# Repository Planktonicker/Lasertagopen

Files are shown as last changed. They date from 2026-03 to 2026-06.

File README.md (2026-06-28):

There is an error with the PCB wiring for the battery, please do not use the PCB design, or edit it

🔫 Open Laser Tag (ESP32 Arena System)

Welcome to Open Laser Tag, a fully open-source, highly scalable, and professional-grade laser tag system built on the ESP32 platform.
This project allows you to build custom laser tag blasters with OLED HUDs, tactile controls, and massive outdoor range, all tied together by a central "Cheap Yellow Display" (CYD) touch server that hosts a live, cyberpunk-themed web dashboard for up to 64 players.
The original intent was to create an easy to setup lasertag game to undercut vendors who charge exhorbitant prices for a game. This hopefullt allows more educator such as myself to have access to easily available laser tag.

✨ Key Features

Massive Scalability: Play backyard games (up to 10 players) using the CYD's built-in Wi-Fi Hub, or scale up to massive 64-player arena matches using a standard, offline Wi-Fi router.
Smart Networking: Blasters and servers automatically search for a central router. If one isn't found, they seamlessly fall back to local Hub mode. No internet connection is ever required.
Live Web Dashboard: The CYD Server hosts a mobile-responsive web dashboard. Game masters can change rules, start/stop matches, and view live K/D/A telemetry from their smartphones.
Esports Scoreboard Overlay: The web dashboard features a dynamic, full-screen overlay for laptops/TVs that automatically divides into quadrants based on active teams (perfect for spectator displays).
Extreme Range Optics: Utilizes a custom 5V-driven TSAL6100 IR circuit paired with a 20mm plano-convex lens for 50+ meter outdoor "sniper" range.
On-the-fly Configuration: Blasters feature a hidden configuration menu (via the rotary encoder) to change Gun IDs, Teams, and Roles without needing to reflash the code.

🛠️ Hardware Requirements

The system is broken down into two main components: The Blasters and The Server.

The Blaster (Gun) BOM

Microcontroller: ESP32 38-Pin DevKitC (WROOM-32)
Display: 1.3" SH1106 I2C OLED (White or Blue)
Controls: * KY-040 Rotary Encoder (For volume, reloading, and menus)
KW12 Microswitch (For the main trigger)
Audio: Passive Piezo Buzzer (5V)

IR Optics:

Transmitter: TSAL6100 (940nm 5mm LED) + 2N2222 Transistor + 20Ω Resistor and 1000ohm resistor
Receiver: TSOP38238 (38kHz) x 3
Lens: 20mm Plano-Convex Lens (Mounted exactly ~21.7mm from the IR LED die)

Power: 18650 Battery + V8 Battery Shield (1-way) + Master Toggle Switch

The Server (Command Center)

Microcontroller/Display: ESP32-2432S028R "Cheap Yellow Display" (2.8" TFT with Touch)
(Alternative): Standard ESP32 with a 2.2" ST7789 TFT display.
Network: Any cheap, standard Wi-Fi router (for 50+ player games).

🔌 Crucial Wiring & Hardware Notes

If you are building this from scratch, pay close attention to these engineering details:
The 5V Laser Circuit: The ESP32's 3.3V pins cannot provide enough power for outdoor IR range. You must route 5V directly from the battery shield to the TSAL6100 LED, using a 2N2222 transistor as a switch controlled by the ESP32 (protected by a 1kΩ base resistor).
Battery Voltage Divider: Because the 18650 shield regulates output to a flat 5V, the ESP32 cannot natively read the battery's decay. You must wire a 100kΩ/100kΩ voltage divider directly from the raw battery (B+ pad) to an ESP32 ADC pin (IO34) to get accurate battery percentages on the OLED.
Multiple IR Receivers: If you want to add sensors to a headband or the sides of the blaster, wire multiple TSOP38238 receivers in Parallel (All VCCs together, all GNDs together, all OUTs together).
Trigger Pull-ups: The KW12 Trigger microswitch connects to GND and an ESP32 GPIO pin. No external resistors are needed; the software uses INPUT_PULLUP.

💻 Software & Installation

This project is built using PlatformIO (via VS Code). Using the Arduino IDE is not recommended due to library dependency management.

Setup Instructions

Clone this repository and open the project folder in VS Code with the PlatformIO extension installed.
The platformio.ini file will automatically download the correct libraries (like LovyanGFX or TFT_eSPI / Adafruit_ILI9341 depending on your screen hardware).
Connect your ESP32 or CYD via USB.
Click Upload in PlatformIO.

📡 Network & Operation Guide

How to Start a Match

(Optional) Power the Router: If playing a massive game, plug in your dedicated LaserArena Wi-Fi router. (Do not plug it into the internet).
Boot the CYD Server: Plug the CYD into a USB power bank. It will search for the router for 10 seconds.
If it finds it, it joins and shows a green [LA] tag.
If not, it creates its own Wi-Fi bubble and shows a yellow [LAH] tag.

Boot the Blasters: Turn on the guns. They will automatically hunt for the network and sync with the CYD Server.
Join the Dashboard: Connect your Smartphone or Laptop to the Wi-Fi network (LaserArena or LaserTag_Hub).

⚠️ IMPORTANT: Accessing the Web Dashboard

Modern devices (especially MacBooks and iPhones) use Secure DNS or Apple Private Relay, which breaks custom local domain names like lasertagarena.game.
To guarantee access to the command center, type the raw IP address directly into your browser:
If using the Router [LA]: Go to http://192.168.1.100
If using the CYD Hub [LAH]: Go to http://192.168.4.1

Managing Teams

You can change a player's team in three different ways:
On the Gun: The player turns the rotary encoder while in the lobby.
On the CYD: The Game Master taps the player's ID on the physical CYD Scoreboard tab.
On the Web App: The Game Master taps the player's row on their smartphone dashboard.

3D prints

Included the F3D files in case you want to edit, the main body hosues all the goods, the extention helps to convert it into a full tagger with grip and nerf stock adapter. Do note you need 3 IR receiver fore this build, feel free to add or remove to your needs. wire them in parrallel

📜 License

lasertagopen is open-source and licensed under the [GNU AFFERO GENERAL PUBLIC LICENSE
Version 3].
If you wish to use this project in a closed-source or proprietary
commercial product, please contact chengxinze96@gmail,com for a commercial license.
Build, modify, and dominate the arena!

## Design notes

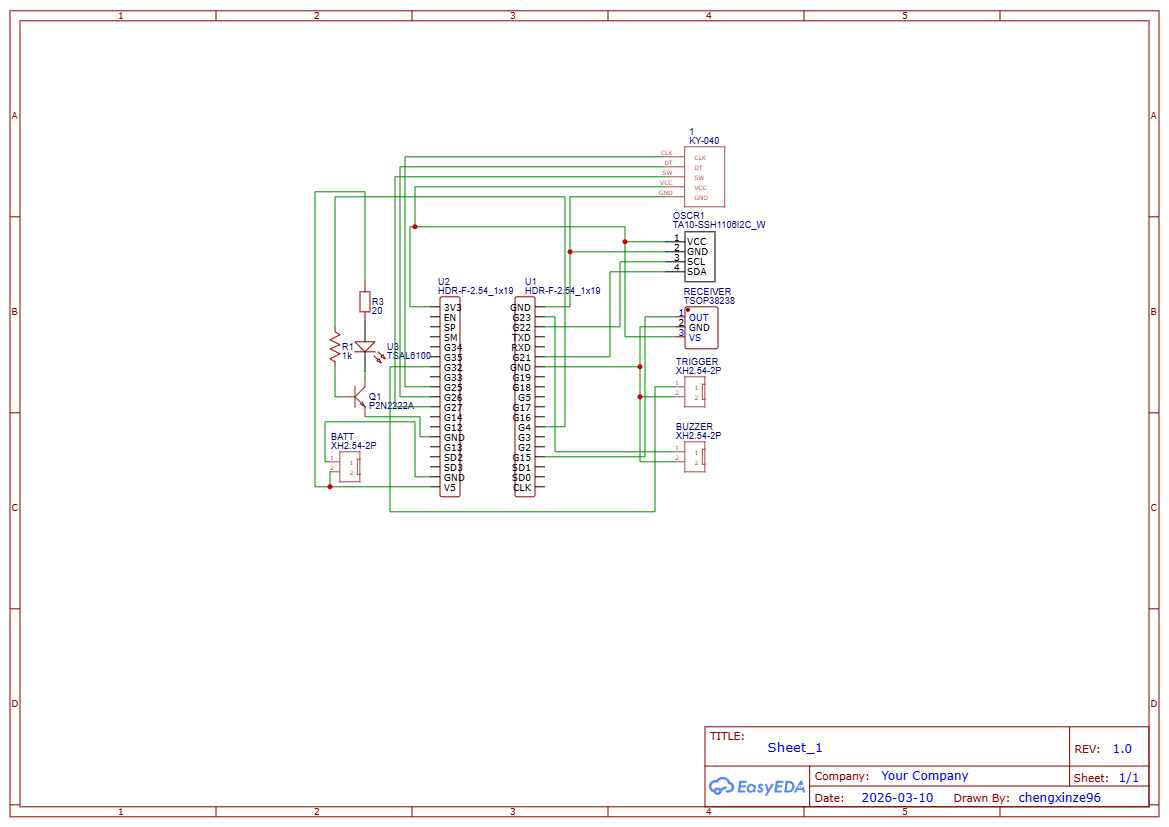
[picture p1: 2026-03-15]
pcb/Schematic_lasertag_2026-03-15.png

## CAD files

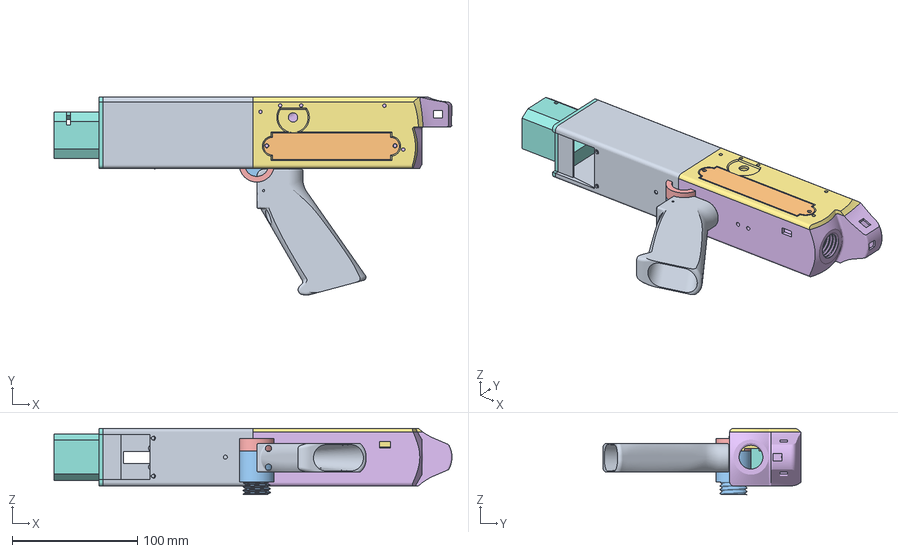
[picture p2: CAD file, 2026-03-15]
3dpint/LASERTAGV3.3mf
318.0 x 158.4 x 53.0 mm
AR_Pistol_Grip_Smooth (1)
Battery cover
Main body
Panel
Stock
pistol grip body

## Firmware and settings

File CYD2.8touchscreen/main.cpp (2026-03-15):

#include <Arduino.h>
#include <WiFi.h>
#include <WebServer.h>
#include <DNSServer.h>
#include <SPI.h>
#include <Adafruit_GFX.h>
#include <Adafruit_ILI9341.h>
#include <XPT2046_Touchscreen.h>

// --- CYD TOUCHSCREEN PINS (VSPI) ---
#define XPT2046_IRQ  36
#define XPT2046_MOSI 32
#define XPT2046_MISO 39
#define XPT2046_CLK  25
#define XPT2046_CS   33

// --- CYD TFT SCREEN PINS (HSPI) ---
#define TFT_MISO 12
#define TFT_MOSI 13
#define TFT_CLK  14
#define TFT_CS   15
#define TFT_DC   2
#define TFT_RST  -1
#define TFT_BL   21 // Backlight

// Initialize dual SPI buses for CYD
XPT2046_Touchscreen ts(XPT2046_CS, XPT2046_IRQ);
SPIClass tftSpi = SPIClass(HSPI);
Adafruit_ILI9341 tft = Adafruit_ILI9341(&tftSpi, TFT_DC, TFT_CS, TFT_RST);
WebServer server(80);
DNSServer dnsServer; 
const byte DNS_PORT = 53;

// --- SERVER VARIABLES ---
const char* apSSID = "LaserTag_Hub";
const char* apPass = "pewpewpew";
const char* routerSSID   = "LaserArena";
const char* routerPass   = "pewpewpew";
const char* customDomain = "lasertagarena.game"; 
bool usingExternalRouter = false; 

// --- GAME STATE SYNCED TO GUNS ---
int hostStatus = 0; // 0=Lobby, 1=Running, 2=Kill All
int baseDamage = 50; 
int configLives = 3;
int configMags = 5;
int configHealth = 100;
int gameMode = 0; // 0=Combat, 1=Unlimited

#define MAX_PLAYERS 64

// --- SCOREBOARD TRACKING ---
struct PlayerRecord {
  int id;
  int team;
  int kills;
  int deaths;
  int assists;
  bool active;
};
PlayerRecord players[MAX_PLAYERS];
int playerCount = 0;

// --- UI STATE ---
int currentScreen = 0; // 0=Main, 1=Setup1, 2=Setup2, 4=Scoreboard
unsigned long gameStartTime = 0;
unsigned long lastTimerUpdate = 0;
int scoreboardOffset = 0; // Tracks which page of players we are viewing

// Cyberpunk / Neon Colors
#define COLOR_WHITE     0xFFFF
#define COLOR_BLACK     0x0000
#define C_BG            tft.color565(5, 5, 10)    // Void Black/Deep Blue
#define C_CYAN          tft.color565(0, 255, 255) // Primary Neon
#define C_MAGENTA       tft.color565(255, 0, 255) // Secondary Neon
#define C_GREEN         tft.color565(0, 255, 100) // Success/Active
#define C_RED           tft.color565(255, 0, 100) // Warning/Kill
#define C_YELLOW        tft.color565(255, 255, 0) // Alerts
#define C_GREY          tft.color565(80, 80, 100) // Inactive outlines

// --- FORWARD DECLARATIONS ---
void drawMainScreen();
void drawSetupScreen1();
void drawSetupScreen2();
void drawScoreboardScreen();

PlayerRecord* getPlayer(int id) {
  if (id <= 0) return nullptr;
  for(int i=0; i<MAX_PLAYERS; i++) {
    if(players[i].active && players[i].id == id) return &players[i];
  }
  for(int i=0; i<MAX_PLAYERS; i++) {
    if(!players[i].active) {
      players[i].id = id;
      players[i].team = 1;
      players[i].kills = 0;
      players[i].deaths = 0;
      players[i].assists = 0;
      players[i].active = true;
      playerCount++;
      return &players[i];
    }
  }
  return nullptr;
}

// --- WEB SERVER ENDPOINTS ---
void handleRoot() {
  int teamKills[5] = {0, 0, 0, 0, 0};
  bool teamActive[5] = {false, false, false, false, false};
  int activeTeamCount = 0; 
  
  for(int i = 0; i < MAX_PLAYERS; i++) {
    if(players[i].active) {
      teamKills[players[i].team] += players[i].kills;
      teamActive[players[i].team] = true;
    }
  }
  
  // Count how many teams are playing to calculate grid layout
  for(int t = 1; t <= 4; t++) {
    if(teamActive[t]) activeTeamCount++;
  }

  String html = "<!DOCTYPE html><html><head><title>Arena Command</title>";
  html += "<meta name='viewport' content='width=device-width, initial-scale=1.0, maximum-scale=1.0, user-scalable=no, viewport-fit=cover'>";
  
  html += "<style>";
  html += "* { box-sizing: border-box; -webkit-tap-highlight-color: transparent; }";
  html += "body { font-family: -apple-system, system-ui, sans-serif; background: #050510; color: #0ff; margin: 0; padding: env(safe-area-inset-top) 15px 40px 15px; }";
  html += ".card { background: rgba(0, 255, 255, 0.08); padding: 20px; border: 1px solid #0ff; border-radius: 20px; margin-bottom: 20px; box-shadow: 0 10px 40px rgba(0,0,0,0.7); }";
  html += "h1 { font-size: 26px; text-align: center; color: #fff; text-shadow: 0 0 15px #0ff; margin: 25px 0; letter-spacing: 1px; }";
  html += "h2 { font-size: 13px; margin-top: 0; border-bottom: 1px solid rgba(0, 255, 255, 0.2); padding-bottom: 12px; margin-bottom: 15px; text-transform: uppercase; letter-spacing: 2px; color: rgba(255,255,255,0.7); }";
  
  html += "button { width: 100%; padding: 22px; margin-bottom: 15px; background: #001a1a; border: 2px solid #0ff; color: #0ff; border-radius: 14px; font-weight: bold; font-size: 18px; transition: 0.1s; cursor: pointer; }";
  html += "button:active { transform: scale(0.97); background: #0ff; color: #000; }";
  html += ".btn-red { border-color: #f0f; color: #f0f; background: #1a001a; }";
  html += ".btn-green { border-color: #0f0; color: #0f0; background: #001a00; }";
  
  html += ".grid { display: flex; flex-wrap: wrap; gap: 15px; }";
  html += ".grid > div { flex: 1 1 calc(50% - 15px); min-width: 100px; }"; // Reduced min-width slightly to fit 5 boxes better
  html += ".score-grid { display: grid; grid-template-columns: repeat(auto-fit, minmax(280px, 1fr)); gap: 20px; }";
  
  html += "label { font-size: 10px; display: block; margin-bottom: 8px; color: #fff; opacity: 0.8; font-weight: 800; letter-spacing: 1px; }";
  html += "input, select { width: 100%; padding: 16px; background: #000; color: #fff; border: 1px solid #0ff; border-radius: 12px; font-size: 18px; outline: none; -webkit-appearance: none; }";
  
  html += "table { width: 100%; text-align: center; border-collapse: collapse; margin-top: 10px; }";
  html += "th, td { padding: 12px 5px; border-bottom: 1px solid rgba(255, 255, 255, 0.1); font-size: 15px; }";
  html += "th { font-size: 10px; opacity: 0.5; color: #fff; }";
  html += ".kd-val { font-weight: bold; color: #fff; }";
  html += "tr.player-row { cursor: pointer; transition: background 0.2s; }"; 
  html += "tr.player-row:hover { background: rgba(255, 255, 255, 0.05); }"; 
  html += "tr.player-row:active { background: rgba(0, 255, 255, 0.2); }"; 

  // --- ESPORTS FULL SCREEN CSS ---
  html += "#fs-overlay{display:none;position:fixed;top:0;left:0;width:100vw;height:100vh;background-color:#050510;background-size:40px 40px;background-image:linear-gradient(to right, rgba(0,255,255,0.05) 1px, transparent 1px),linear-gradient(to bottom, rgba(0,255,255,0.05) 1px, transparent 1px);z-index:9999;padding:30px;flex-direction:column;overflow:hidden;box-sizing:border-box;} ";
  html += "#fs-overlay.active{display:flex;} ";
  html += ".fs-header{display:flex;justify-content:space-between;align-items:center;margin-bottom:20px;} ";
  html += ".fs-title{font-size:28px;font-weight:900;letter-spacing:2px;color:#fff;margin:0;text-shadow:0 0 10px rgba(255,255,255,0.5);} ";
  html += ".fs-grid{display:grid;gap:30px;flex:1;min-height:0;} ";
  html += ".fs-grid[data-teams='1']{grid-template-columns:1fr;} ";
  html += ".fs-grid[data-teams='2']{grid-template-columns:1fr 1fr;} ";
  html += ".fs-grid[data-teams='3'],.fs-grid[data-teams='4']{grid-template-columns:1fr 1fr;grid-template-rows:1fr 1fr;} ";
  html += ".fs-team-panel{border:2px solid;border-radius:12px;display:flex;flex-direction:column;background:rgba(0,0,0,0.5);box-shadow:inset 0 0 50px rgba(0,0,0,0.8);overflow:hidden;} ";
  html += ".fs-team-header{padding:20px;display:flex;justify-content:space-between;align-items:center;background:rgba(255,255,255,0.1);border-bottom:2px solid;} ";
  html += ".fs-team-name{font-size:24px;font-weight:900;letter-spacing:2px;} ";
  html += ".fs-team-score{font-size:32px;font-weight:900;} ";
  html += ".fs-table-wrap{overflow-y:auto;flex:1;padding:0 10px;} ";
  html += ".fs-table{width:100%;border-collapse:collapse;} ";
  html += ".fs-table th{position:sticky;top:0;background:#000;padding:15px;font-size:14px;text-transform:uppercase;color:rgba(255,255,255,0.5);z-index:2;} ";
  html += ".fs-table td{padding:15px;font-size:20px;border-bottom:1px solid rgba(255,255,255,0.05);text-align:center;} ";
  html += ".fs-close{padding:10px 30px;background:transparent;border:2px solid #f0f;color:#f0f;border-radius:8px;cursor:pointer;font-size:18px;font-weight:bold;width:auto;margin:0;transition:0.2s;} ";
  html += ".fs-close:hover{background:#f0f;color:#000;} ";
  html += "</style>";
  
  html += "<script>";
  html += "function swapTeam(id, currentTeam) {";
  html += "  let nextTeam = currentTeam + 1; if(nextTeam > 4) nextTeam = 1;";
  html += "  fetch('/join?id=' + id + '&team=' + nextTeam).then(() => location.reload());";
  html += "}";
  html += "function toggleFS() {";
  html += "  let el = document.getElementById('fs-overlay');";
  html += "  let isActive = el.classList.toggle('active');";
  html += "  sessionStorage.setItem('fs-active', isActive ? 'true' : 'false');";
  html += "}";
  html += "document.addEventListener('DOMContentLoaded', function() {";
  html += "  if(sessionStorage.getItem('fs-active') === 'true') {";
  html += "    document.getElementById('fs-overlay').classList.add('active');";
  html += "  }";
  html += "});";
  html += "setInterval(function(){ location.reload(); }, 12000);";
  html += "</script>";
  html += "</head><body>";
  
  html += "<h1>ARENA COMMAND ";
  html += usingExternalRouter ? "<span style='color:#0f0; font-size:16px;'>[LA ROUTER]</span>" : "<span style='color:#ff0; font-size:16px;'>[LAH HUB]</span>";
  html += "</h1>";
  
  html += "<div class='card'><h2>STATUS: " + String(hostStatus == 1 ? "RUNNING" : (hostStatus == 0 ? "LOBBY" : "KILL ALL")) + "</h2>";
  
  html += "<form action='/set'>";
  if (hostStatus == 0) html += "<button name='cmd' value='start' class='btn-green'>START MISSION</button>";
  else html += "<button name='cmd' value='lobby'>RETURN LOBBY</button>";
  html += "<button name='cmd' value='kill' class='btn-red' style='border-style:dashed; margin-top:10px;'>EMERGENCY KILL ALL</button>";
  html += "</form></div>";
  
  html += "<div class='card'><h2>TEAM STANDINGS <span style='font-size:10px; color:#f0f; float:right;'>(TAP ROW TO SWAP)</span></h2>";
  if (playerCount == 0) {
    html += "<div style='padding:40px; text-align:center; opacity:0.3;'>NO OPERATORS DETECTED</div>";
  } else {
    html += "<div class='score-grid'>";
    for(int t = 1; t <= 4; t++) {
      if(!teamActive[t]) continue;
      
      String tName = "UNKNOWN"; String tCol = "#fff"; String bgCol = "rgba(255,255,255,0.05)";
      if (t == 1) { tName = "RED TEAM"; tCol = "#ff3366"; bgCol = "rgba(255,51,102,0.1)"; }
      else if (t == 2) { tName = "BLUE TEAM"; tCol = "#00ffff"; bgCol = "rgba(0,255,255,0.1)"; }
      else if (t == 3) { tName = "GREEN TEAM"; tCol = "#00ff88"; bgCol = "rgba(0,255,136,0.1)"; }
      else if (t == 4) { tName = "YELLOW TEAM"; tCol = "#ffcc00"; bgCol = "rgba(255,204,0,0.1)"; }

      html += "<div style='background:" + bgCol + "; border-left: 4px solid " + tCol + "; padding: 15px; border-radius: 8px;'>";
      html += "<div style='display:flex; justify-content:space-between; align-items:center; margin-bottom: 10px;'>";
      html += "<span style='color:" + tCol + "; font-weight:bold; font-size:18px;'>" + tName + "</span>";
      html += "<span style='color:#fff; font-size:22px; font-weight:bold;'>" + String(teamKills[t]) + " KILLS</span></div>";
      html += "<table><tr><th>GUN</th><th>K</th><th>D</th><th>K/D</th></tr>";
      for(int i = 0; i < MAX_PLAYERS; i++) {
        if(players[i].active && players[i].team == t) {
          float kd = players[i].deaths == 0 ? (float)players[i].kills : (float)players[i].kills / players[i].deaths;
          
          html += "<tr class='player-row' onclick='swapTeam(" + String(players[i].id) + "," + String(players[i].team) + ")'>";
          html += "<td style='color:#fff; font-weight:bold;'>#" + String(players[i].id) + "</td>";
          html += "<td>" + String(players[i].kills) + "</td>";
          html += "<td>" + String(players[i].deaths) + "</td>";
          html += "<td class='kd-val'>" + String(kd, 1) + "</td></tr>";
        }
      }
      html += "</table></div>";
    }
    html += "</div>";
  }
  
  // Dashboard Action Buttons
  html += "<div style='display:flex; gap:10px; margin-top:20px;'>";
  html += "<button type='button' class='btn-green' style='margin:0; padding:12px; font-size:12px; flex:1; border-style:solid;' onclick='toggleFS()'>⛶ ENLARGE SCOREBOARD</button>";
  html += "<form action='/clearscores' style='margin:0; flex:1;'><button class='btn-red' style='margin:0; padding:12px; font-size:12px; width:100%; border-style:dotted;'>RESET SCOREBOARD</button></form>";
  html += "</div></div>";
  
  html += "<div class='card'><h2>DIRECTIVES</h2><form action='/setrules'><div class='grid'>";
  html += "<div><label>MODE</label><select name='mode'><option value='0' "+String(gameMode==0?"selected":"")+">Combat</option><option value='1' "+String(gameMode==1?"selected":"")+">Unlimited</option></select></div>";
  html += "<div><label>HEALTH (HP)</label><input type='number' name='hp' value='"+String(configHealth)+"'></div>";
  html += "<div><label>DAMAGE</label><input type='number' name='dmg' value='"+String(baseDamage)+"'></div>";
  html += "<div><label>LIVES</label><input type='number' name='lvs' value='"+String(configLives)+"'></div>";
  // FIX: Added the missing MAGS input field here!
  html += "<div><label>MAGS</label><input type='number' name='mags' value='"+String(configMags)+"'></div>";
  html += "</div><button type='submit' style='margin-top:25px; background:#0ff; color:#000;'>SYNC DIRECTIVES</button></form></div>";
  
  // =====================================================================
  // ESPORTS FULL SCREEN SCOREBOARD OVERLAY
  // =====================================================================
  html += "<div id='fs-overlay'>";
  html += "<div class='fs-header'><h2 class='fs-title'>// COMBAT TELEMETRY : LIVE</h2><button class='fs-close' onclick='toggleFS()'>EXIT</button></div>";
  html += "<div class='fs-grid' data-teams='" + String(activeTeamCount) + "'>";

  if (activeTeamCount > 0) {
    for(int t = 1; t <= 4; t++) {
      if(!teamActive[t]) continue;
      String tName = "UNKNOWN"; String tCol = "#fff"; 
      if (t == 1) { tName = "RED TEAM"; tCol = "#ff3366"; }
      else if (t == 2) { tName = "BLUE TEAM"; tCol = "#00ffff"; }
      else if (t == 3) { tName = "GREEN TEAM"; tCol = "#00ff88"; }
      else if (t == 4) { tName = "YELLOW TEAM"; tCol = "#ffcc00"; }
      
      html += "<div class='fs-team-panel' style='border-color:" + tCol + ";'>";
      html += "<div class='fs-team-header' style='border-bottom-color:" + tCol + ";'>";
      html += "<span class='fs-team-name' style='color:" + tCol + ";'>" + tName + "</span>";
      html += "<span class='fs-team-score' style='color:#fff;'>" + String(teamKills[t]) + " KILLS</span></div>";
      html += "<div class='fs-table-wrap'><table class='fs-table'>";
      html += "<tr><th style='text-align:left;'>OPERATOR</th><th>KILLS</th><th>DEATHS</th><th>K/D RATIO</th></tr>";
      for(int i = 0; i < MAX_PLAYERS; i++) {
        if(players[i].active && players[i].team == t) {
          float kd = players[i].deaths == 0 ? (float)players[i].kills : (float)players[i].kills / players[i].deaths;
          html += "<tr class='player-row' onclick='swapTeam(" + String(players[i].id) + "," + String(players[i].team) + ")'>";
          html += "<td style='color:#fff; font-weight:bold; text-align:left;'>GUN #" + String(players[i].id) + "</td>";
          html += "<td>" + String(players[i].kills) + "</td>";
          html += "<td>" + String(players[i].deaths) + "</td>";
          html += "<td style='color:#fff; font-weight:bold;'>" + String(kd, 1) + "</td></tr>";
        }
      }
      html += "</table></div></div>";
    }
  } else {
    html += "<div style='color:#fff; opacity:0.3; text-align:center; padding:50px; font-size:24px; grid-column:1/-1;'>NO OPERATORS DETECTED</div>";
  }
  
  html += "</div></div>"; // End fs-grid and fs-overlay
  html += "</body></html>";
  
  server.send(200, "text/html", html);
}

void handleJoin() {
  if (server.hasArg("id")) {
    int prevCount = playerCount;
    PlayerRecord* p = getPlayer(server.arg("id").toInt());
    
    if (p && server.hasArg("team")) {
      p->team = server.arg("team").toInt();
    }
  }
  server.send(200, "text/plain", "OK");
  if (currentScreen == 4) drawScoreboardScreen();
}

void handleHitRecord() {
  if (server.hasArg("isDeath") && server.arg("isDeath") == "1") {
    if (server.hasArg("shooterID")) {
      PlayerRecord* s = getPlayer(server.arg("shooterID").toInt());
      if(s) s->kills++;
    }
    if (server.hasArg("victimID")) {
      PlayerRecord* v = getPlayer(server.arg("victimID").toInt());
      if(v) v->deaths++;
    }
  }
  server.send(200, "text/plain", "Recorded");
  if (currentScreen == 4) drawScoreboardScreen();
}

void handleClearScores() {
  for(int i=0; i<MAX_PLAYERS; i++) players[i].active = false;
  playerCount = 0;
  scoreboardOffset = 0; // Reset page to 1
  server.sendHeader("Location", "/");
  server.send(303);
  if (currentScreen == 4) drawScoreboardScreen();
}

void handleStatus() {
  String assignedTeam = "0";
  if (server.hasArg("id")) {
    PlayerRecord* p = getPlayer(server.arg("id").toInt());
    if (p) assignedTeam = String(p->team); 
  }

  String payload = String(hostStatus) + "," + String(baseDamage) + "," + String(configLives) + "," + String(configMags) + "," + String(configHealth) + "," + String(gameMode) + "," + assignedTeam;
  server.send(200, "text/plain", payload);
}

void handleSet() {
  if (server.hasArg("cmd")) {
    String cmd = server.arg("cmd");
    if (cmd == "start") { hostStatus = 1; gameStartTime = millis(); }
    else if (cmd == "lobby") hostStatus = 0;
    else if (cmd == "kill") hostStatus = 2;
  }
  
  server.sendHeader("Location", "/");
  server.send(303);
  
  if(currentScreen == 0) drawMainScreen();
}

void handleSetRules() {
  if (server.hasArg("hp")) configHealth = server.arg("hp").toInt();
  if (server.hasArg("dmg")) baseDamage = server.arg("dmg").toInt();
  if (server.hasArg("lvs")) configLives = server.arg("lvs").toInt();
  if (server.hasArg("mags")) configMags = server.arg("mags").toInt();
  if (server.hasArg("mode")) gameMode = server.arg("mode").toInt();
  
  server.sendHeader("Location", "/");
  server.send(303);
  
  // Instantly redraw if CYD is looking at the settings page while rules are updated via Web
  if(currentScreen == 1) drawSetupScreen1();
  else if(currentScreen == 2) drawSetupScreen2();
}

// --- SMART NETWORK ROUTINE ---
void connectToNetwork() {
  tft.fillScreen(C_BG);
  tft.setTextColor(C_CYAN);
  tft.setTextSize(2);
  tft.setCursor(10, 120); tft.print("SEARCHING FOR");
  tft.setCursor(10, 150); tft.print("ARENA ROUTER...");

  WiFi.mode(WIFI_STA);
  IPAddress local_IP(192, 168, 1, 100);
  IPAddress gateway(192, 168, 1, 1);
  IPAddress subnet(255, 255, 255, 0);
  WiFi.config(local_IP, gateway, subnet);
  WiFi.begin(routerSSID, routerPass);

  int attempts = 0;
  while (WiFi.status() != WL_CONNECTED && attempts < 20) { 
    delay(500);
    attempts++;
  }

  tft.fillScreen(C_BG);
  if (WiFi.status() == WL_CONNECTED) {
    usingExternalRouter = true;
    tft.setTextColor(C_GREEN);
    tft.setCursor(10, 120); tft.print("ROUTER FOUND!");
    tft.setCursor(10, 150); tft.print("IP: 192.168.1.100");
    dnsServer.start(DNS_PORT, customDomain, WiFi.localIP());
  } else {
    usingExternalRouter = false;
    tft.setTextColor(C_YELLOW);
    tft.setCursor(10, 120); tft.print("ROUTER NOT FOUND");
    tft.setCursor(10, 150); tft.print("STARTING CYD HUB");
    WiFi.disconnect();
    WiFi.mode(WIFI_AP);
    WiFi.softAP(apSSID, apPass);
    dnsServer.start(DNS_PORT, customDomain, WiFi.softAPIP());
  }
  delay(2000); 
}

void setupHost() {
  server.on("/", handleRoot);
  server.on("/join", handleJoin);
  server.on("/hit", handleHitRecord);
  server.on("/status", handleStatus);
  
  // Web dashboard controls
  server.on("/set", handleSet);
  server.on("/setrules", handleSetRules);
  server.on("/clearscores", handleClearScores);
  
  server.begin();
}

// --- CYBERPUNK UI DRAWING HELPERS ---

void drawHeader(const char* title) {
  tft.fillRect(0, 0, 240, 25, C_BG); 
  tft.drawLine(0, 25, 240, 25, C_CYAN);
  tft.drawLine(0, 27, 240, 27, C_CYAN); 
  
  tft.setTextColor(C_CYAN);
  tft.setTextSize(2);
  tft.setCursor(5, 5);
  tft.print(title);
  
  // Network Tag - Dynamically right-aligned
  tft.setTextSize(2);
  String netTag = usingExternalRouter ? "[LA]" : "[HUB]";
  int textWidth = netTag.length() * 12; 
  tft.setCursor(235 - textWidth, 5); 
  tft.setTextColor(usingExternalRouter ? C_GREEN : C_YELLOW);
  tft.print(netTag);
}
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
void loop() {
  dnsServer.processNextRequest();
  server.handleClient(); 

  if (ts.tirqTouched() && ts.touched()) {
    TS_Point p = ts.getPoint();
    int mapX = map(p.x, 300, 3800, 0, 240);
    int mapY = map(p.y, 300, 3800, 0, 320);
    processTouch(mapX, mapY);
    delay(200); 
  }

  // Update massive timer
  if (currentScreen == 0 && hostStatus == 1) {
    if (millis() - lastTimerUpdate >= 1000) {
      lastTimerUpdate = millis();
      unsigned long elapsedSeconds = (millis() - gameStartTime) / 1000;
      char buf[10]; sprintf(buf, "%d:%02d", (int)(elapsedSeconds/60), (int)(elapsedSeconds%60));

      // Wipe inner box
      tft.fillRoundRect(23, 78, 194, 94, 4, C_BG); 
      
      tft.setTextColor(C_CYAN);
      tft.setTextSize(6);
      
      int textWidth = strlen(buf) * 36;
      tft.setCursor(20 + (200 - textWidth) / 2, 101); 
      tft.print(buf);
    }
  }
}

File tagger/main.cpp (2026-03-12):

#include <Arduino.h>
#include <Wire.h>
#include <Adafruit_GFX.h>
#include <Adafruit_SH110X.h>
#include <WiFi.h>
#include <WebServer.h>
#include <HTTPClient.h>
#include <IRsend.h>
#include <IRrecv.h>
#include <IRutils.h>
#include <Preferences.h>

// =========================================================================
// PIN DEFINITIONS
// =========================================================================
#define PIN_OLED_SDA    21
#define PIN_OLED_SCL    22
#define OLED_ADDR       0x3C

#define PIN_ENC_CLK     25
#define PIN_ENC_DT      26
#define PIN_ENC_SW      27

#define PIN_TRIGGER     32  
#define PIN_BUZZER      23
#define PIN_IR_TX       4
#define PIN_IR_RX       15
#define PIN_BATT        34
#define PIN_DEBUG_HIT   14 // Touch this pin to GND to simulate getting shot!

// =========================================================================
// HARDWARE OBJECTS
// =========================================================================
Adafruit_SH1106G display = Adafruit_SH1106G(128, 64, &Wire, -1);
IRsend irsend(PIN_IR_TX);
IRrecv irrecv(PIN_IR_RX);
decode_results results;
Preferences preferences;

// =========================================================================
// STATE VARIABLES
// =========================================================================

// Hardware states
int lastCLK      = HIGH;
int lastSW       = HIGH;
int lastTrigger  = HIGH;
int lastDebugHit = HIGH;

// Debounce & Hold Timers 
unsigned long configHoldTimer = 0;
unsigned long swHoldTimer     = 0;
unsigned long lastTurnTime    = 0;
unsigned long lastButtonTime  = 0;
bool reloadTriggered          = false;

// System States
enum GameState { BOOT_MENU, HOST_LOBBY, TEAM_SELECT, PLAYING, RESPAWNING, DEAD, CONFIG_MENU, RELOADING };
GameState currentState = BOOT_MENU;

// Permanent Device Settings
int savedRole  = 1;     
int myGunID    = 1;       
int baseDamage = 50;   

// Player Variables
bool isHost      = false;
int selectedTeam = 1; 

// Combat Rules & Live Stats
int lives        = 3;
int hp           = 100;
int magazines    = 5;
int ammo         = 7; 
int maxAmmo      = 7;
unsigned long respawnTimer = 0;

// Config Menu Variables
int configMenuIndex  = 0;
bool configIsEditing = false;

// Host Server Variables
const char* apSSID       = "LaserTag_Hub";
const char* apPass       = "pewpewpew";
const char* routerSSID   = "LaserArena";
const char* routerPass   = "pewpewpew";
String serverIP          = "http://192.168.4.1"; // Defaults to CYD Hub, updates dynamically
int lastHostStatus       = 0;         

// Host Configurable Rules
int configLives      = 3;
int configMags       = 5;
int configHealth     = 100;
int gameMode         = 0; // 0 = Combat, 1 = Unlimited
bool registeredWithServer = false;


// =========================================================================
// AUDIO & UTILITY SYSTEMS
// =========================================================================

void playSound(int type) {
  switch(type) {
    case 1: tone(PIN_BUZZER, 1200, 50); break;  // Shoot
    case 2: tone(PIN_BUZZER, 400, 150); delay(150); tone(PIN_BUZZER, 600, 150); break; // Reload Complete
    case 3: tone(PIN_BUZZER, 200, 500); break;  // Hit
    case 4: tone(PIN_BUZZER, 100, 1000); break; // Death
    case 5: tone(PIN_BUZZER, 800, 100); break;  // Error/Menu beep
    case 6: tone(PIN_BUZZER, 1500, 30); break;  // Reloading tick
  }
  delay(10); // Timer breathing room
}

int getBatteryPercent() {
  int raw = analogRead(PIN_BATT);
  float voltage = (raw / 4095.0) * 3.3 * 2.0; 
  int percent = map(voltage * 100, 320, 420, 0, 100);
  
  if (percent > 100) percent = 100;
  if (percent < 0) percent = 0;
  
  return percent;
}

const char* getTeamName(int t) {
  if (t == 1) return "RED";
  if (t == 2) return "BLUE";
  if (t == 3) return "GREEN";
  if (t == 4) return "YELLOW";
  return "UNK";
}

// =========================================================================
// DISPLAY ROUTINES
// =========================================================================

void drawUI() {
  display.clearDisplay();
  
  // --------------------------------------------------
  // CONFIG MENU
  // --------------------------------------------------
  if (currentState == CONFIG_MENU) {
    display.fillRect(0, 0, 128, 12, SH110X_WHITE);
    display.setTextColor(SH110X_BLACK);
    display.setTextSize(1);
    display.setCursor(10, 2); 
    display.print("--- CONFIG MODE ---");
    
    // Config: Role
    if (configMenuIndex == 0) display.fillRect(0, 14, 128, 12, SH110X_WHITE);
    display.setTextColor(configMenuIndex == 0 ? SH110X_BLACK : SH110X_WHITE);
    display.setCursor(4, 16); 
    display.print("Role: "); 
    display.print(savedRole == 0 ? "[ASK]" : (savedRole == 1 ? "[PLAYER]" : "[HOST]"));
    if (configIsEditing && configMenuIndex == 0) display.print(" <");

    // Config: Gun ID
    display.setTextColor(SH110X_WHITE);
    if (configMenuIndex == 1) display.fillRect(0, 26, 128, 12, SH110X_WHITE);
    display.setTextColor(configMenuIndex == 1 ? SH110X_BLACK : SH110X_WHITE);
    display.setCursor(4, 28); 
    display.print("Gun ID: "); 
    display.print(myGunID); 
    if (configIsEditing && configMenuIndex == 1) display.print(" <");

    // Config: Base Damage
    display.setTextColor(SH110X_WHITE);
    if (configMenuIndex == 2) display.fillRect(0, 38, 128, 12, SH110X_WHITE);
    display.setTextColor(configMenuIndex == 2 ? SH110X_BLACK : SH110X_WHITE);
    display.setCursor(4, 40); 
    display.print("Base Dmg: "); 
    display.print(baseDamage); 
    if (configIsEditing && configMenuIndex == 2) display.print(" <");

    // Config: Save
    display.setTextColor(SH110X_WHITE);
    if (configMenuIndex == 3) display.fillRect(0, 52, 128, 12, SH110X_WHITE);
    display.setTextColor(configMenuIndex == 3 ? SH110X_BLACK : SH110X_WHITE);
    display.setCursor(10, 54); 
    display.print(">> SAVE & REBOOT <<");
    
    display.display();
    return;
  }

  // --------------------------------------------------
  // GLOBAL TOP STATUS BAR
  // --------------------------------------------------
  display.fillRect(0, 0, 128, 12, SH110X_WHITE);
  display.setTextColor(SH110X_BLACK);
  display.setTextSize(1);
  display.setCursor(2, 2); 
  
  if (isHost) {
    display.print("HOST SERVER");
  } else {
    display.print("GUN "); 
    display.print(myGunID);
    if (WiFi.status() == WL_CONNECTED) display.print(" [WIFI]");
  }
  
  // Battery Indicator
  int batt = getBatteryPercent();
  if (batt == 100) display.setCursor(100, 2);
  else if (batt >= 10) display.setCursor(106, 2);
  else display.setCursor(112, 2);
  display.print(batt); 
  display.print("%");
  
  display.setTextColor(SH110X_WHITE);
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
